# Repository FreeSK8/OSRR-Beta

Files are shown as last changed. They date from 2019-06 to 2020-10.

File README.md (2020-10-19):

# OSRR-Beta

## LEGACY OSRR Beta Project - retired 2019 - See FreeSK8 Remote Project for continued development. 

OSRR- Open Source Racing Remote, which serves as an open spec reference design for a robust remote control device, for use with VESC/Unity based PEVs. 

### Authors & Contributors:
Andrew Dresner

Renee Love

For information on setup & usage, please see the Wiki: 

https://github.com/FreeSK8/OSRR/wiki

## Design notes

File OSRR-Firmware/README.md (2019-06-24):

# OSRR Firmware

Place in Arduino folder. Tested on Arduino version 1.8.9

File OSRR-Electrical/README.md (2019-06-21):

# OSRR Electrical

EagleCAD 9.3.2

TODO: EagleCAD Libraries, BOM

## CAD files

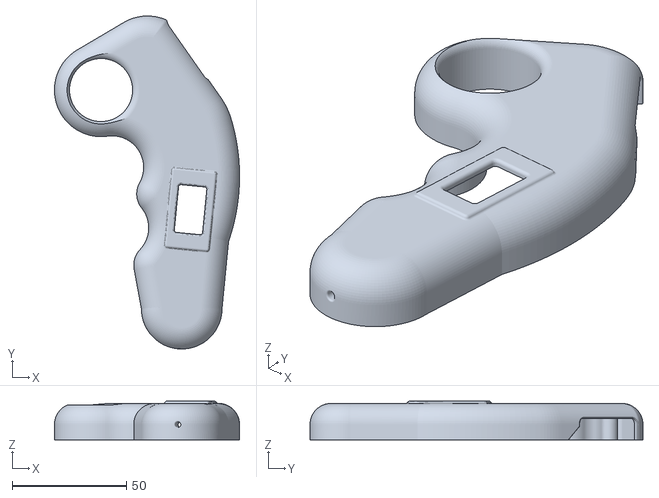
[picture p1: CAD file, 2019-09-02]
OSRR-Mechanical/OSRR-HMP-TopShell-v3.stl
81.1 x 145.8 x 17.0

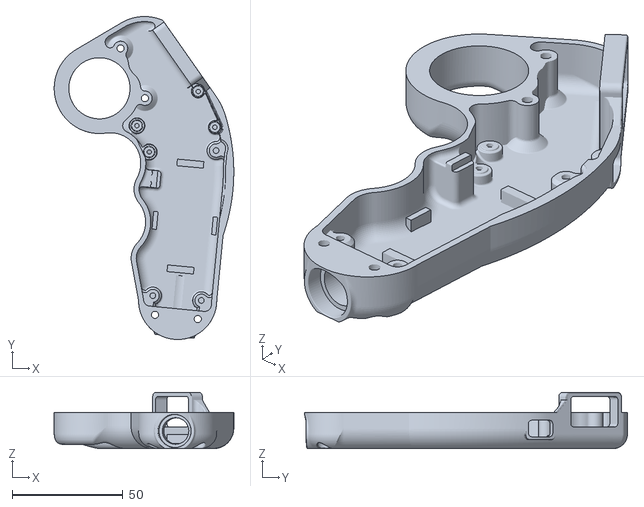
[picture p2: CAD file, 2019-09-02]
OSRR-Mechanical/OSRR-HMP-BottomShell-v3.stl
81.1 x 145.8 x 25.5

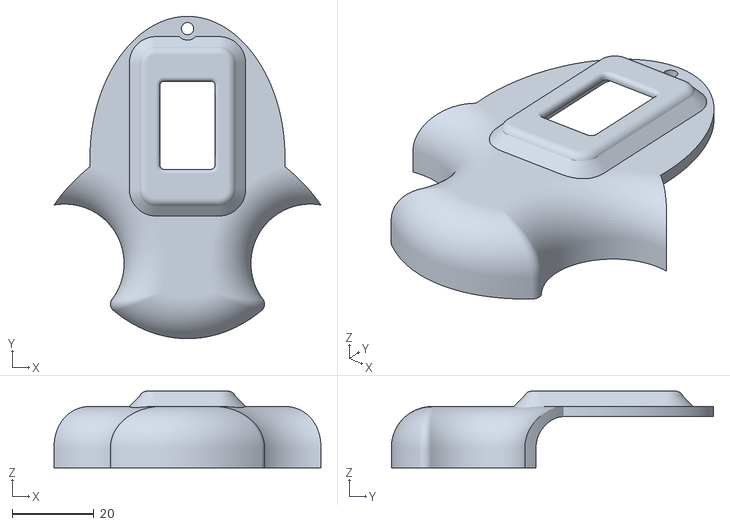
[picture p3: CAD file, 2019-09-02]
OSRR-Mechanical/OSRR-Bruce-TopShell-v1.stl
65.2 x 78.7 x 18.8

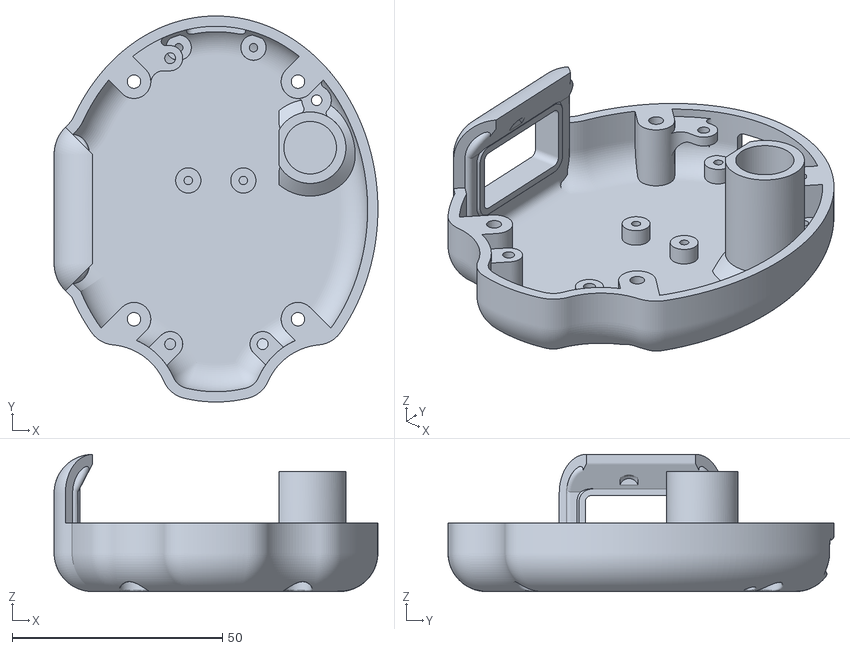
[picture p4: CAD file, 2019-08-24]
OSRR-Mechanical/OSRR-HHG-BottomShell-v2.stl
77.0 x 91.8 x 32.6

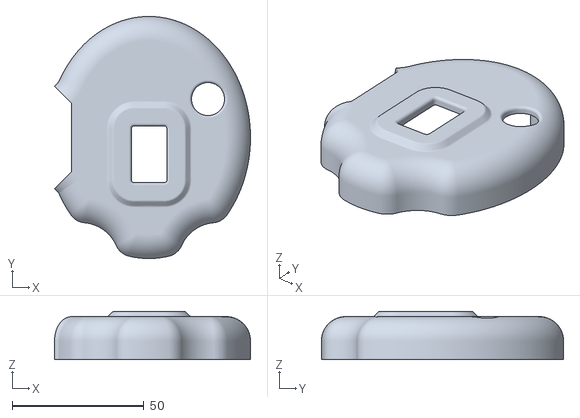
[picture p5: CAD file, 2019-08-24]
OSRR-Mechanical/OSRR-HHG-TopShell-v2.stl
74.3 x 91.8 x 18.3

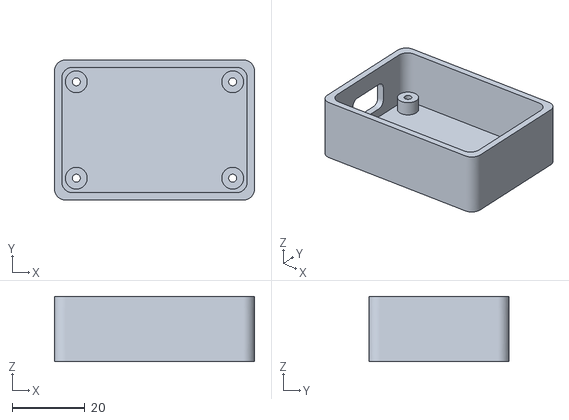
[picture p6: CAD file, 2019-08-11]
OSRR-Mechanical/Receiver-BottomShell.stl
55.0 x 38.5 x 18.0

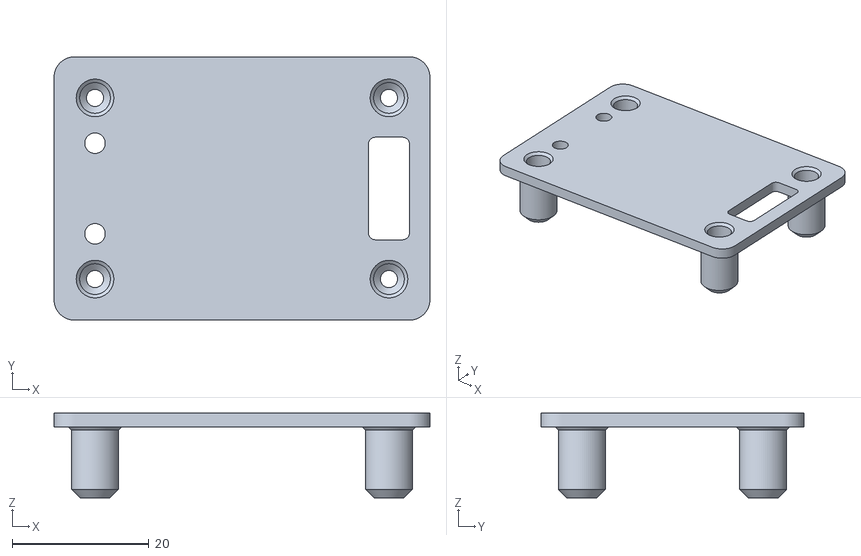
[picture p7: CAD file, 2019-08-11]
OSRR-Mechanical/Receiver-TopShell.stl
55.0 x 38.5 x 12.4

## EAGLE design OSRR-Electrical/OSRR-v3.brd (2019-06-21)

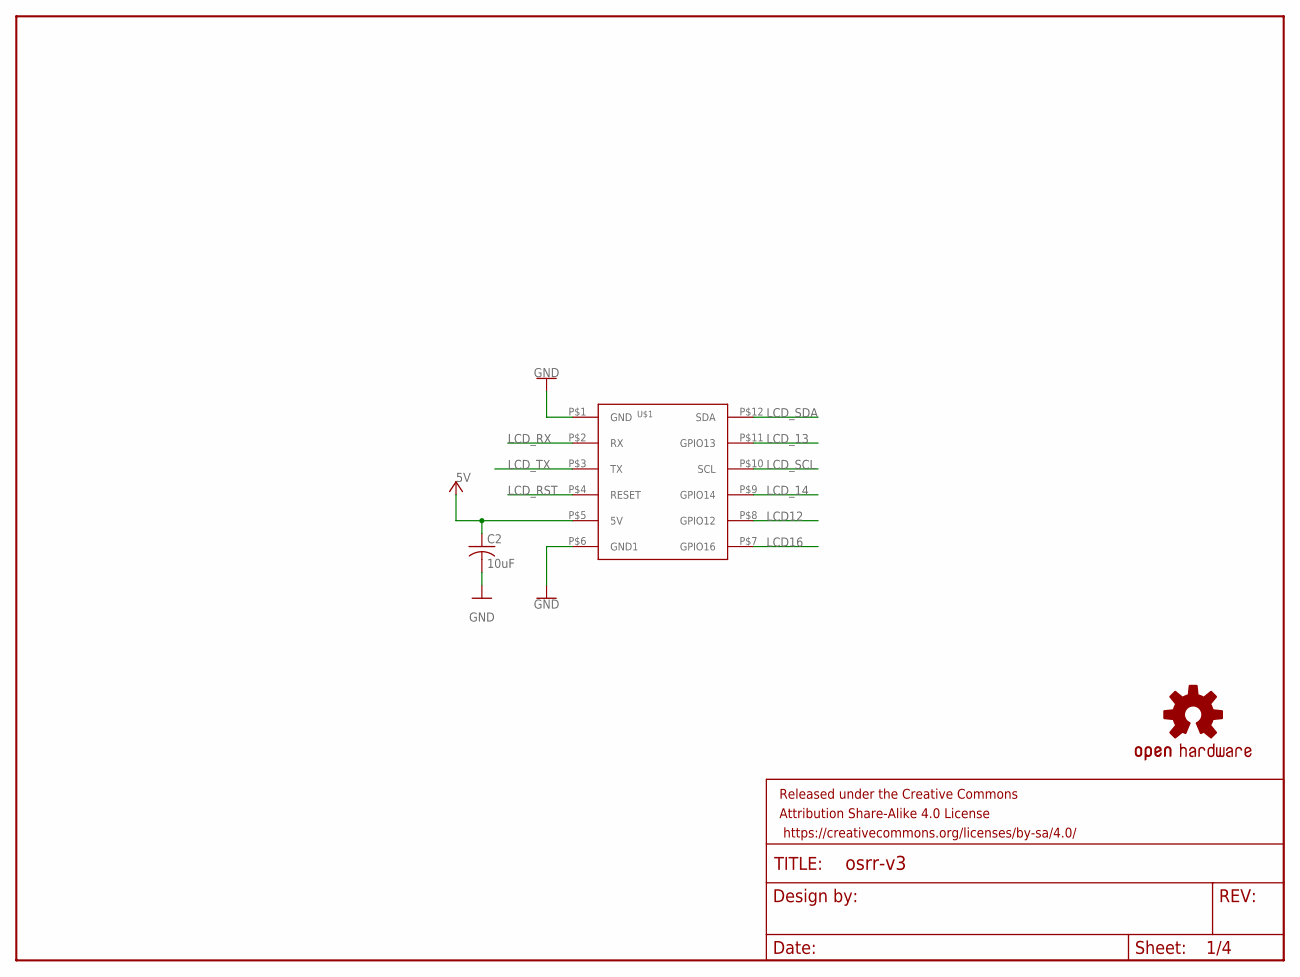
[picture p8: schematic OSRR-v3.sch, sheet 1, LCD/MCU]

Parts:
C2: 10uF; C0603
FRAME1: FRAME-LETTER; CREATIVE_COMMONS
LOGO1: OSHW-LOGOS; OSHW-LOGO-S
U$1: IOD-09; IOD-9TH

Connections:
5V: C2.1, U$1.P$5 (5V); also elsewhere on the board
GND: C2.2, U$1.P$1 (GND), U$1.P$6 (GND1); also elsewhere on the board
LCD12: U$1.P$8 (GPIO12)
LCD16: U$1.P$7 (GPIO16)
LCD_13: U$1.P$11 (GPIO13)
LCD_14: U$1.P$9 (GPIO14)
LCD_RST: U$1.P$4 (RESET)
LCD_RX: U$1.P$2 (RX); also elsewhere on the board
LCD_SCL: U$1.P$10 (SCL); also elsewhere on the board
LCD_SDA: U$1.P$12 (SDA); also elsewhere on the board
LCD_TX: U$1.P$3 (TX); also elsewhere on the board

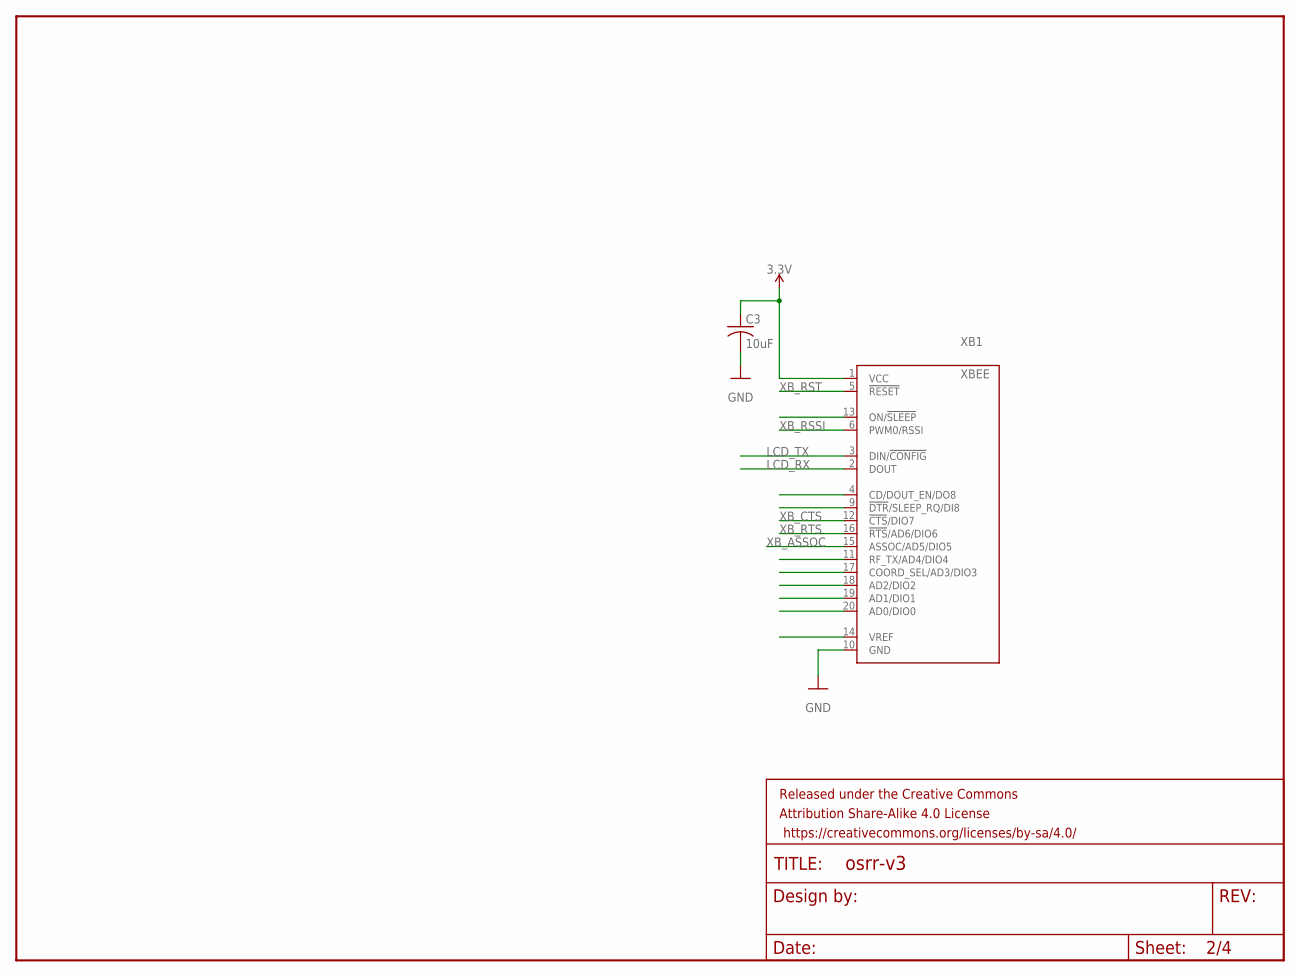
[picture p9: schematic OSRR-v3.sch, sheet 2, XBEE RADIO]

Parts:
C3: 10uF; C0603
FRAME2: FRAME-LETTER; CREATIVE_COMMONS
XB1: XBEE

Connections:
3.3V: C3.1, XB1.1 (VCC); also elsewhere on the board
GND: C3.2, XB1.10 (GND); also elsewhere on the board
LCD_RX: XB1.2 (DOUT); also elsewhere on the board
LCD_TX: XB1.3 (DIN/!CONFIG); also elsewhere on the board
XB_ASSOC: XB1.15 (ASSOC/AD5/DIO5)
XB_CTS: XB1.12 (!CTS!/DIO7)
XB_RSSI: XB1.6 (PWM0/RSSI); also elsewhere on the board
XB_RST: XB1.5 (!RESET)
XB_RTS: XB1.16 (!RTS!/AD6/DIO6)

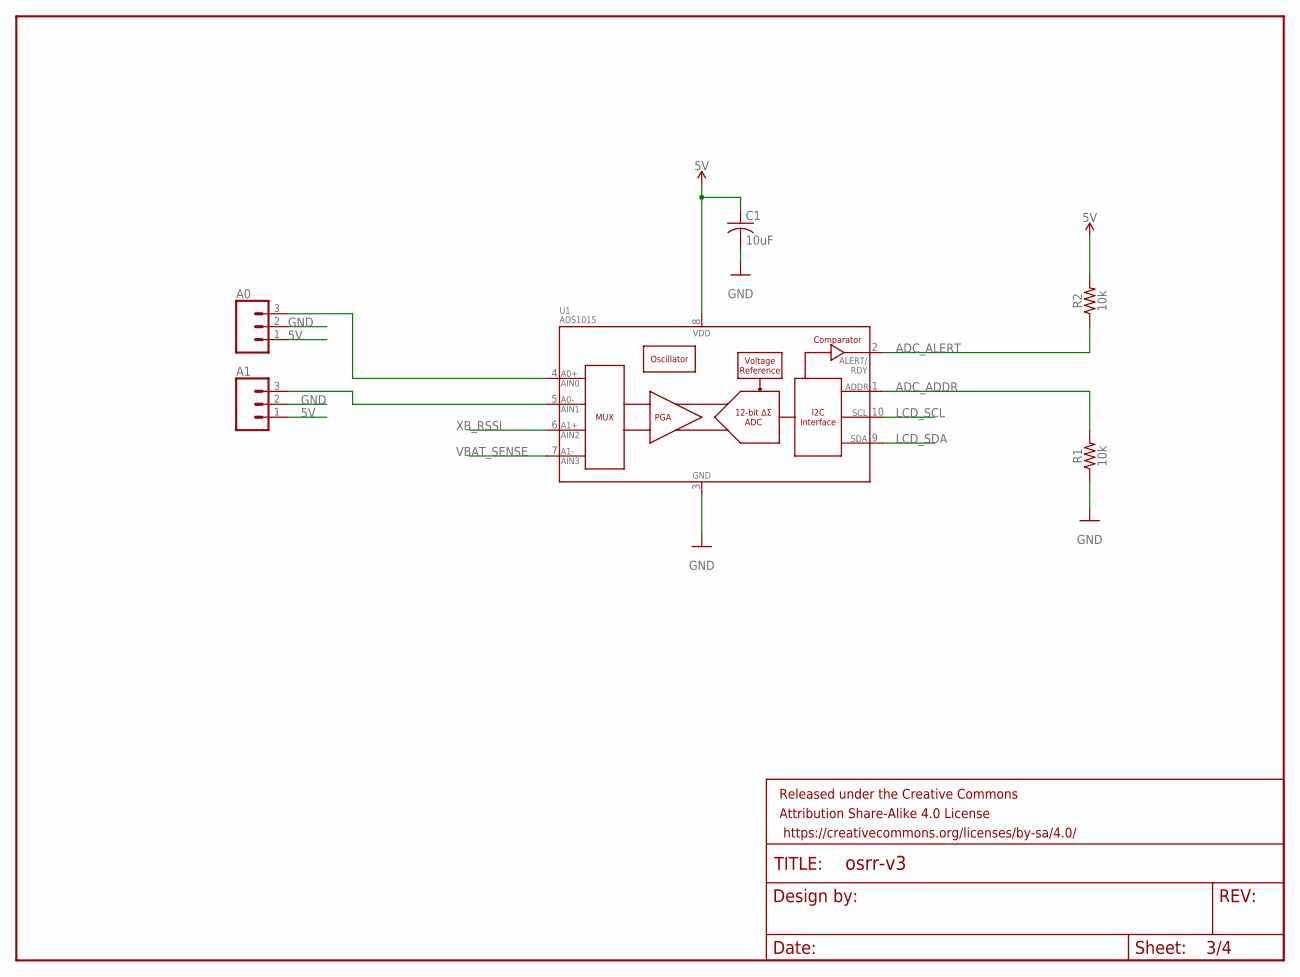
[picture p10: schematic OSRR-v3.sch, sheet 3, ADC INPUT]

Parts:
A0, A1: CONN_03JST-PTH-VERT; JST-3-PTH-VERT
C1: 10uF; C0603
FRAME3: FRAME-LETTER; CREATIVE_COMMONS
R1, R2: 10k; 0603
U1: ADS1015; MSOP10

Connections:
5V: A0.1, A1.1, C1.1, R2.2, U1.8 (VDD); also elsewhere on the board
ADC_ADDR: R1.2, U1.1 (ADDR)
ADC_ALERT: R2.1, U1.2 (ALERT/RDY)
GND: A0.2, A1.2, C1.2, R1.1, U1.3 (VSS); also elsewhere on the board
LCD_SCL: U1.10 (SCL); also elsewhere on the board
LCD_SDA: U1.9 (SDA); also elsewhere on the board
unnamed: A0.3, U1.4 (AIN0)
unnamed: A1.3, U1.5 (AIN1)
VBAT_SENSE: U1.7 (AIN3); also elsewhere on the board
XB_RSSI: U1.6 (AIN2); also elsewhere on the board

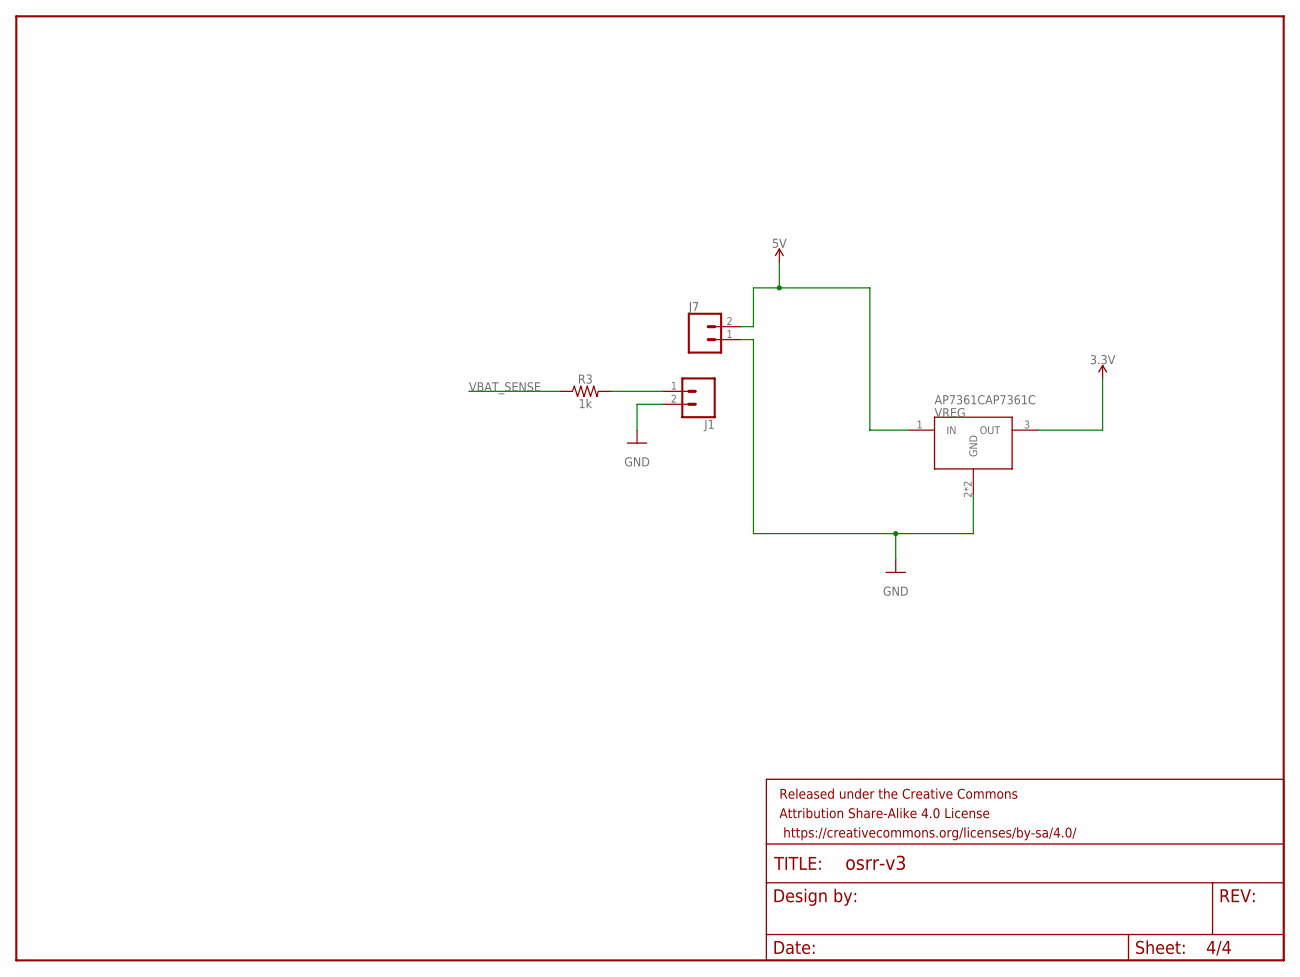
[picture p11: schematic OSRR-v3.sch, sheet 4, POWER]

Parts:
FRAME4: FRAME-LETTER; CREATIVE_COMMONS
J1: CONN_02; 1X02
J7: CONN_02-JST-2-PTH-NO_SILK; JST-2-PTH-NS
R3: 1k; 0603
VREG: AP7361CAP7361C; SOT230P700X180-4

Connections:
3.3V: VREG.3 (OUT); also elsewhere on the board
5V: J7.2, VREG.1 (IN); also elsewhere on the board
GND: J1.2, J7.1, VREG.2 (GND), VREG.4 (GND); also elsewhere on the board
unnamed: J1.1, R3.2
VBAT_SENSE: R3.1; also elsewhere on the board

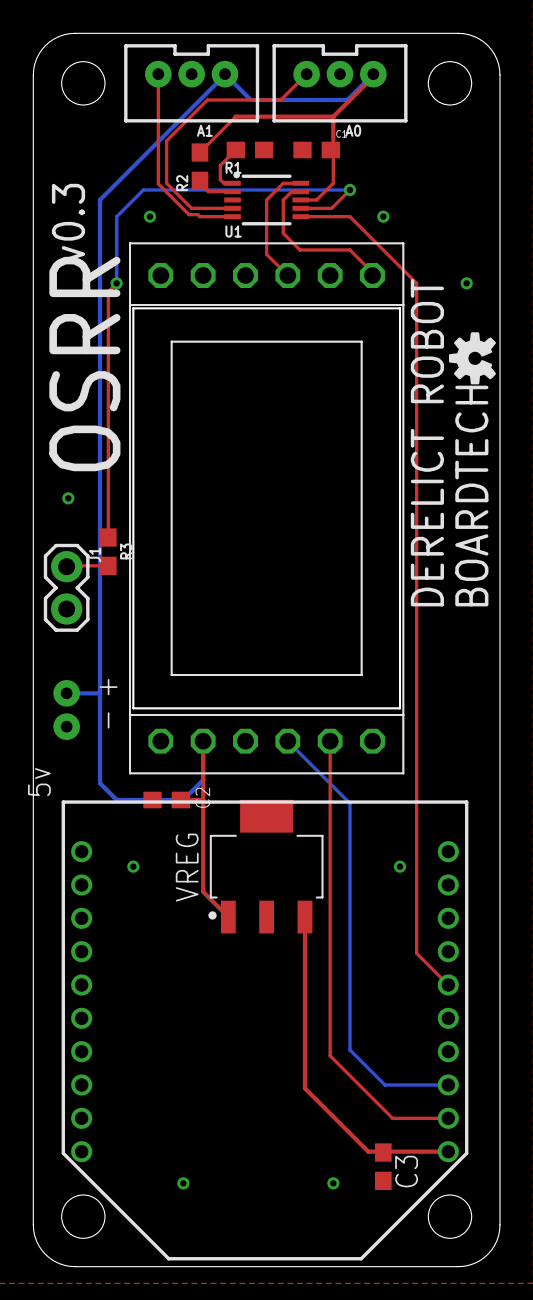
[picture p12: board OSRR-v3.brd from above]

Board: 2 copper layers, 28.0 x 74.0 mm, 19 parts (0 on the bottom side), 14 nets.

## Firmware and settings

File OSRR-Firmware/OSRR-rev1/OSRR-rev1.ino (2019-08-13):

/*
  Name:    OSRR-rev1.ino
  Created: 01-03-2019
  Author:  DerelictRobot / Andrew Dresner
  Source Attribution: SolidGeek/StefanMeGit
  Description:  Null.
*/

#include <Wire.h>
#include "ESP8266WiFi.h"
#include "GFX4dIoD9.h"
#include <Adafruit_ADS1015.h>
#include "config.h"

#ifdef ESC_VESC
#include <VescUart.h>
#endif
#ifdef ESC_UNITY
#include <VescUartUnity.h>
#endif


/** Initiate VescUart class */
// Initiate VescUart class for UART communication
#ifdef ESC_UNITY
VescUartUnity UART;
#endif
#ifdef ESC_VESC
VescUart UART;
#endif

GFX4dIoD9 gfx = GFX4dIoD9();
Adafruit_ADS1015 ads;     /* Use thi for the 12-bit version */

void setup() {

  delay(100);
  
  gfx.begin();
  gfx.Cls();
  gfx.ScrollEnable(false);
  gfx.BacklightOn(true);
  gfx.Orientation(PORTRAIT);
  //  gfx.SmoothScrollSpeed(5);
  gfx.TextColor(CYAN, BLACK); gfx.Font(2);  gfx.TextSize(1);
  // gfx.TextWindow(0, 0, 80, 82, ORANGE, BLACK);
  gfx.println("      ");
  gfx.println("  OSRR");
  gfx.println(" ONLINE");
  delay(500);
  gfx.Cls();
  delay(100);

  /** Setup UART port (Serial on Atmega32u4) */
  Serial.begin(115200);
  //  while (!Serial) {
  //    ;
  //  }
  delay(50);
  /** Define which ports to use as UART */
  UART.setSerialPort(&Serial);

  delay(50);
  updateLCD();                                //Update values on LCD
  gfx.RoundRect(2, 135, 52, 155, 3, LIME);    //Draw Remote Battery Meter Border
  delay(50);
  ads.setGain(GAIN_TWOTHIRDS);  // 2/3x gain +/- 6.144V  1 bit = 3mV      0.1875mV (default)
  //  ads.setGain(GAIN_ONE);        // 1x gain   +/- 4.096V  1 bit = 2mV      0.125mV
  ads.begin();
  delay(50);

  UART.nunchuck.lowerButton = false;
  
  calculateRatios();
  
}





void loop() {

  thumbwheelVal0 = ads.readADC_SingleEnded(0);
  // thumbwheelVal1 = ads.readADC_SingleEnded(1);
  if (thumbwheelVal0 > adc_max_limit) {
    throttle = 127;
  }
  else
  {
    throttle = map(thumbwheelVal0, min_ads, max_ads, 0, 255);
    throttle = constrain(throttle, 0, 255);
  }
  /** The lowerButton is used to set cruise control ON */
  //      UART.nunchuck.lowerButton = true;

  /** The lowerButton is used to set cruise control OFF */
  UART.nunchuck.lowerButton = false;
  /** The valueY is used to control the speed, where 127 is the middle = no current */
  UART.nunchuck.valueY = throttle;
  /** Call the function setNunchuckValues to send the current nunchuck values to the VESC */
  UART.setNunchuckValues();
  delay(20); //approx 48hz

  //remoteRSSIRaw = ads.readADC_SingleEnded(2);


  unsigned long currentMillis = millis();

  if (currentMillis - previousMillis >= interval) {
    previousMillis = currentMillis;
    updateLCD();
  }

  yield(); // Required for ESP
}

void updateLCD()  {
  if ( UART.getVescValues() ) {
#ifdef IMPERIAL
    int speedValue = ((ratioRpmSpeed * UART.data.rpm) * 0.621371);
#endif
#ifdef METRIC
    int speedValue = (ratioRpmSpeed * UART.data.rpm);
#endif
    gfx.MoveTo(15, 10);
    gfx.TextColor(YELLOW, BLACK); gfx.Font(2);  gfx.TextSize(3);
    if (speedValue >= 10) {
      gfx.print(String(speedValue));
    }
    else if (speedValue < 0) {
      gfx.print(String(speedValue));
    }
    else if (speedValue <= 9) {
      gfx.print("0");
      gfx.print(String(speedValue));
    }


    gfx.MoveTo(12, 70);
    gfx.TextColor(RED, BLACK); gfx.Font(2);  gfx.TextSize(1);
    gfx.print("V ");
    gfx.print(String(UART.data.inpVoltage, 1));

    //    gfx.TextColor(CYAN, BLACK);
    //    gfx.print("M ");
    //    int currentMotorWatts = (UART.data.avgMotorCurrent * 2) * (UART.data.dutyCycleNow * UART.data.inpVoltage);
    //    if (currentMotorWatts >= 100) {
    //      gfx.println(String(currentMotorWatts));
    //    } else if (currentMotorWatts >= 10) {
    //      gfx.print("0");
    //      gfx.println(String(currentMotorWatts));
    //    } else if (currentMotorWatts <= 9) {
    //      gfx.print("00");
    //      gfx.println(String(currentMotorWatts));
    //    }
    //
    //
    //
    gfx.MoveTo(12, 90);
    gfx.TextColor(ORANGE, BLACK);
    gfx.print("W ");
#ifdef ESC_UNITY
    int currentBatWatts = (UART.data.avgInputCurrent) * (UART.data.inpVoltage);
#endif    
#ifdef ESC_VESC
    int currentBatWatts = (UART.data.avgInputCurrent * 2) * (UART.data.inpVoltage);
#endif    
    if (currentBatWatts >= 1000) {
      gfx.print(String(currentBatWatts));
    }
    else if (currentBatWatts < 0) {
      gfx.print("-RGN");
    }
    else if (currentBatWatts >= 100) {
      gfx.print("0");
      gfx.print(String(currentBatWatts));
    }
    else if (currentBatWatts >= 10) {
      gfx.print("00");
      gfx.print(String(currentBatWatts));
    }
    else if (currentBatWatts <= 9) {
      gfx.print("000");
      gfx.print(String(currentBatWatts));
    }

    gfx.MoveTo(12, 110);
    gfx.TextColor(CYAN, BLACK);
    gfx.print("O ");
#ifdef IMPERIAL
    distanceValue = (ratioPulseDistance * UART.data.tachometerAbs) * 0.621371;
#endif
#ifdef METRIC
    distanceValue = (ratioPulseDistance * UART.data.tachometerAbs);
#endif
    gfx.print(String(distanceValue));



    //    successCount++;
    //    gfx.TextColor(CYAN, BLACK); gfx.Font(2);  gfx.TextSize(1);
    //    gfx.println(String(successCount));
    //    gfx.TextColor(RED, BLACK); gfx.Font(2);  gfx.TextSize(1);
    //    gfx.println(String(failCount));

    if (connBlink) {
      gfx.CircleFilled(65, 145, 8, LIMEGREEN);
    } else  {
      gfx.Circle(65, 145, (8), BLACK);
      gfx.Circle(65, 145, (7), BLACK);
      gfx.Circle(65, 145, (6), BLACK);
    }
    connBlink = !connBlink;
  }
  else
  {
    //    failCount++;
    connBlinkCount++;

    if (connBlinkCount >= 5) {
      gfx.CircleFilled(65, 145, 8, YELLOW);
      connBlinkCount = 0;
    }

  }
  updateRemoteBattery();
}

void updateRemoteBattery() {
  int batteryLevel;
  remoteBatRaw = ads.readADC_SingleEnded(3);
  batteryLevel = map(remoteBatRaw, min_ads_bat, max_ads_bat, 0, 100);
  batteryLevel = constrain(batteryLevel, 0, 100);
  remoteBatteryDisplay(batteryLevel);

  //    gfx.MoveTo(12, 64);
  //    gfx.TextColor(RED, BLACK); gfx.Font(2);  gfx.TextSize(1);
  //    gfx.print("R ");
  //    gfx.print(String(remoteBatRaw));

}


void remoteBatteryDisplay(int remoteBatVal) {
  if (remoteBatVal > 95)  {
    gfx.RoundRectFilled(4, 137, 14, 153, 3, RED);
    gfx.RoundRectFilled(16, 137, 26, 153, 3, ORANGE);
    gfx.RoundRectFilled(28, 137, 38, 153, 3, YELLOW);
    if (remoteBatFlash) {
      gfx.RoundRectFilled(40, 137, 50, 153, 3, LIME);
    }
    else  {
      gfx.RoundRectFilled(40, 137, 50, 153, 3, LIMEGREEN);
    }
    remoteBatFlash = !remoteBatFlash;
  }
  else if (remoteBatVal > 70 && remoteBatVal <= 95) {
    gfx.RoundRectFilled(4, 137, 14, 153, 3, RED);
    gfx.RoundRectFilled(16, 137, 26, 153, 3, ORANGE);
    gfx.RoundRectFilled(28, 137, 38, 153, 3, YELLOW);
    gfx.RoundRectFilled(40, 137, 50, 153, 3, LIME);
  }
  else if (remoteBatVal > 50 && remoteBatVal <= 70) {
    gfx.RoundRectFilled(4, 137, 14, 153, 3, RED);
    gfx.RoundRectFilled(16, 137, 26, 153, 3, ORANGE);
    gfx.RoundRectFilled(28, 137, 38, 153, 3, YELLOW);
    gfx.RoundRectFilled(40, 137, 50, 153, 3, BLACK);
  }
  else if (remoteBatVal > 25 && remoteBatVal <= 50) {
    gfx.RoundRectFilled(4, 137, 14, 153, 3, RED);
    gfx.RoundRectFilled(16, 137, 26, 153, 3, ORANGE);
    gfx.RoundRectFilled(28, 137, 38, 153, 3, BLACK);
    gfx.RoundRectFilled(40, 137, 50, 153, 3, BLACK);
  }
  else if (remoteBatVal > 10 && remoteBatVal <= 25) {
    gfx.RoundRectFilled(4, 137, 14, 153, 3, RED);
    gfx.RoundRectFilled(16, 137, 26, 153, 3, BLACK);
    gfx.RoundRectFilled(28, 137, 38, 153, 3, BLACK);
    gfx.RoundRectFilled(40, 137, 50, 153, 3, BLACK);
  }
  else if (remoteBatVal <= 10) {
    if (remoteBatFlash) {
      gfx.RoundRectFilled(4, 137, 14, 153, 3, RED);
    }
    else {
      gfx.RoundRectFilled(4, 137, 14, 153, 3, BLACK);
    }
    remoteBatFlash = !remoteBatFlash;
    gfx.RoundRectFilled(16, 137, 26, 153, 3, BLACK);
    gfx.RoundRectFilled(28, 137, 38, 153, 3, BLACK);
    gfx.RoundRectFilled(40, 137, 50, 153, 3, BLACK);
  }
}

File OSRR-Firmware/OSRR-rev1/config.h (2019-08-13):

#ifndef CONFIG_H
#define CONFIG_H

// - Choose UART protocol:
#define ESC_UNITY             // ESC_UNITY for UART communication with a UNITY
//#define ESC_VESC                // ESC_VESC for UART communication with a VESC 4.12-6.6

// - Choose Metric or Imperial
//#define METRIC
#define IMPERIAL

// Defining variables to hold values for speed and distance calculation
float wheelDiameter = 200;  //Wheel diameter in MM.
float wheelPulley = 60;     //Wheel Pulley Tooth Count
float motorPulley = 15;     //Motor Pulley Tooth Count
float motorPoles = 14;      //Motor Poles - 14 default

float gearRatio;
float ratioRpmSpeed;
float ratioPulseDistance;
float distanceValue;


unsigned long previousMillis = 0;
const long interval = 250;

int16_t thumbwheelVal0;
int16_t thumbwheelVal1;
String command;
int throttle = 127;
int throttleCenterMargin = 5;
bool throttleActive = false;
int min_ads = 0;
int max_ads = 1700;
int adc_max_limit = 2000;


int16_t remoteBatRaw;
int min_ads_bat = 1000;
int max_ads_bat = 1400;
int adc_max_bat_limit = 2000;

int16_t remoteRSSIRaw;

void calculateRatios()  {
  gearRatio = (motorPulley) / (wheelPulley);
  ratioRpmSpeed = (gearRatio * 60 * wheelDiameter * 3.14156) / ((motorPoles / 2) * 1000000);
  ratioPulseDistance = (gearRatio * wheelDiameter * 3.14156) / ((motorPoles * 3) * 1000000);

}


#ifdef ESC_UNITY
// Defining struct to handle callback data for UNITY
struct callback {
  float ampHours;
  float inpVoltage;
  long rpm;
  long tachometerAbs;
  uint8_t headlightActive;
  float avgInputCurrent;
  float avgMotorCurrent0;
  float avgMotorCurrent1;
  float dutyCycleNow0;
  float dutyCycleNow1;
  bool eStopArmed;
  int8_t receiverRssi;
  float filteredFetTemp0;
  float filteredFetTemp1;
  float filteredMotorTemp0;
  float filteredMotorTemp1;
} returnData;
#endif

#ifdef ESC_VESC
// Defining struct to handle callback data for VESC
struct callback {
  float ampHours;
  float inpVoltage;
  long rpm;
  long tachometerAbs;
  uint8_t headlightActive;
  float avgInputCurrent;
  float avgMotorCurrent0;
  float dutyCycleNow0;
  bool eStopArmed;
  int8_t receiverRssi;
  float filteredFetTemp0;
  float filteredMotorTemp0;
} returnData;
#endif


// Defining struct to hold stats
struct stats {
  float maxSpeed;
  long maxRpm;
  float minVoltage;
  float maxVoltage;
};

// Defining variables for speed and distance calculation



bool recievedData = false;
uint32_t lastTimeReceived = 0;
int timeoutMax = 500;
unsigned long lastDataCheck;
bool remoteBatFlash = true;
bool connBlink = true;
int connBlinkCount = 0;
unsigned long failCount = 0;
unsigned long successCount = 0;

//struct vescValues data;

#endif

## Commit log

2019-06-21 Reorg, initial electrical & mechanical push
    [OSRR - Her Majesty's Pleasure.stp, OSRR - Holy Hand Grenade.stp, OSRR-v3.brd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]
2019-06-24 Updated to STL export. rev2 HMP model grip enclosure.
    [HMP-BottomShell-v2.stl, HMP-TopShell-v2.stl, OSRR - Her Majesty's Pleasure.stp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]
2019-06-25 Initial HHG model upload.
    [HHG-BottomShell-v1.stl, HHG-TopShell-v1.stl]
2019-07-28 Added metric option, odometer fix
    [OSRR-rev1.ino]
2019-07-28 Enable remote battery monitor & display
2019-07-28 Battery Monitor updates
2019-07-31 Remote Battery Monitor Updates
2019-07-31 Remote Battery Monitoring Updates
2019-08-11 Enclosure STL updates
    [HHG-BottomShell-v1.stl, HHG-TopShell-v1.stl, HMP-BottomShell-v2.stl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]
2019-08-13 Enclosure updates, HHG display port adj
    [OSRR-Bruce-TopShell-v1.stl, OSRR-HHG-TopShell-v2.stl]
2019-08-16 Bruce topshell adjustment
    [OSRR-Bruce-TopShell-v1.stl]
2019-08-24 HHG updates for leash hole
    [OSRR-HHG-BottomShell-v2.stl, OSRR-HHG-TopShell-v2.stl]
2019-09-02 Bruce updates
    [OSRR-Bruce-TopShell-v1.stl]
2019-09-02 HMP updates
    [OSRR-HMP-BottomShell-v3.stl, OSRR-HMP-TopShell-v3.stl]

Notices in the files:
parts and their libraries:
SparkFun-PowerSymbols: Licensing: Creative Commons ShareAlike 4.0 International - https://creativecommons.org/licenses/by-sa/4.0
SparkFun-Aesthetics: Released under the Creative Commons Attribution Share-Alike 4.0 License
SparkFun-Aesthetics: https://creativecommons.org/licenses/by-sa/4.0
